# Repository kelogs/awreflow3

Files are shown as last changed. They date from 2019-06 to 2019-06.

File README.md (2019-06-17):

# AW reflow 3

awreflow3 is a reflow oven for soldering PCBs based on [Andy's Workshop awreflow2](http://andybrown.me.uk/2015/07/12/awreflow2/). Technically, this repository contains the missing electric diagram and a layout for the oven, with some modifications in order to suit the parts I had lying around. The purpose of this repository is that you can also pull the files and modify them according to your needs.

## Prerequisites

This project has been developed with [KiCad](http://www.kicad-pcb.org/download/)

## Notes

If you have to order the MOC3020 from the schematic you could get a [MOC3023](https://www.arrow.com/en/products/moc3023/isocom) instead and do away with the Q2 transistor and adjoining resistors.

Other things worth mentioning on the actual oven. Get one based on halogen heating elements just like Andy has done. Mine is a quartz elements oven and the PID is totally useless due to its very high inertia. I had to bypass the PID and hardcode some time intervals where power level is 0% and others where power is driven at 100%. 
At 1000W power and and 9L volume my oven can still bake a full tray of leaded solder PCBs, only a bit slower than others. Here is how it looks:





**NOTE** I currently have 9 extra PCBs already made. If you would like one drop me a message here and I'll deliver it for $3.44 + shipping + Paypal taxes

## License
[MIT](https://choosealicense.com/licenses/mit/)

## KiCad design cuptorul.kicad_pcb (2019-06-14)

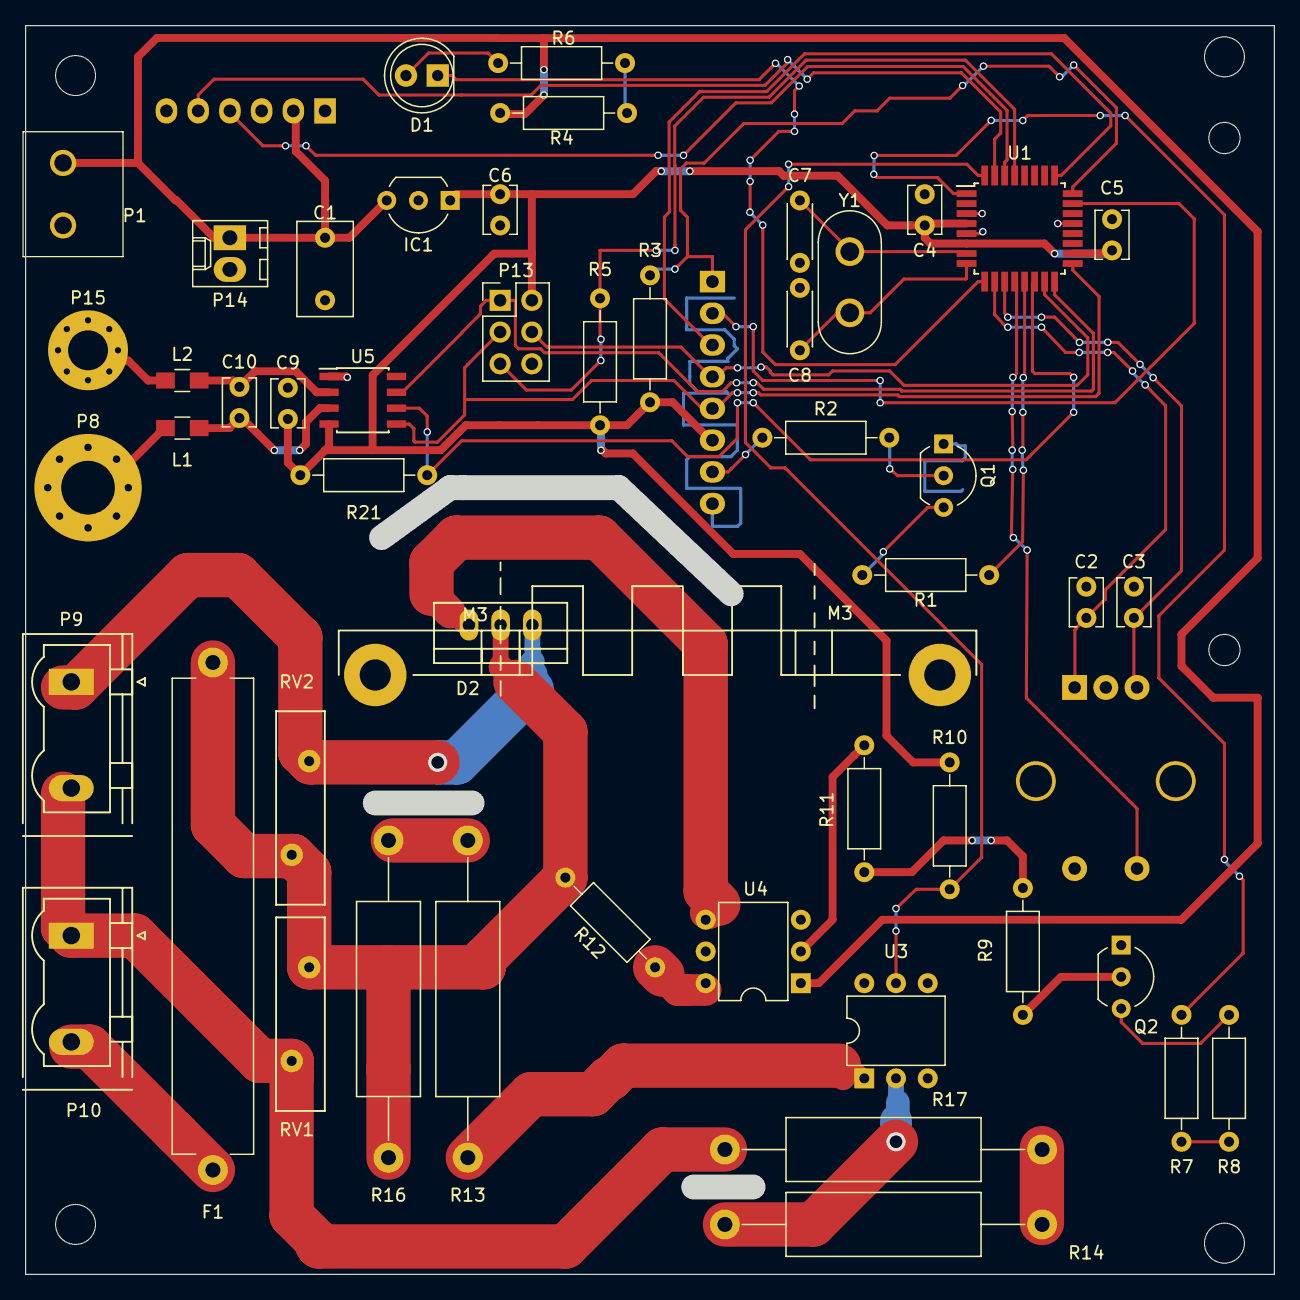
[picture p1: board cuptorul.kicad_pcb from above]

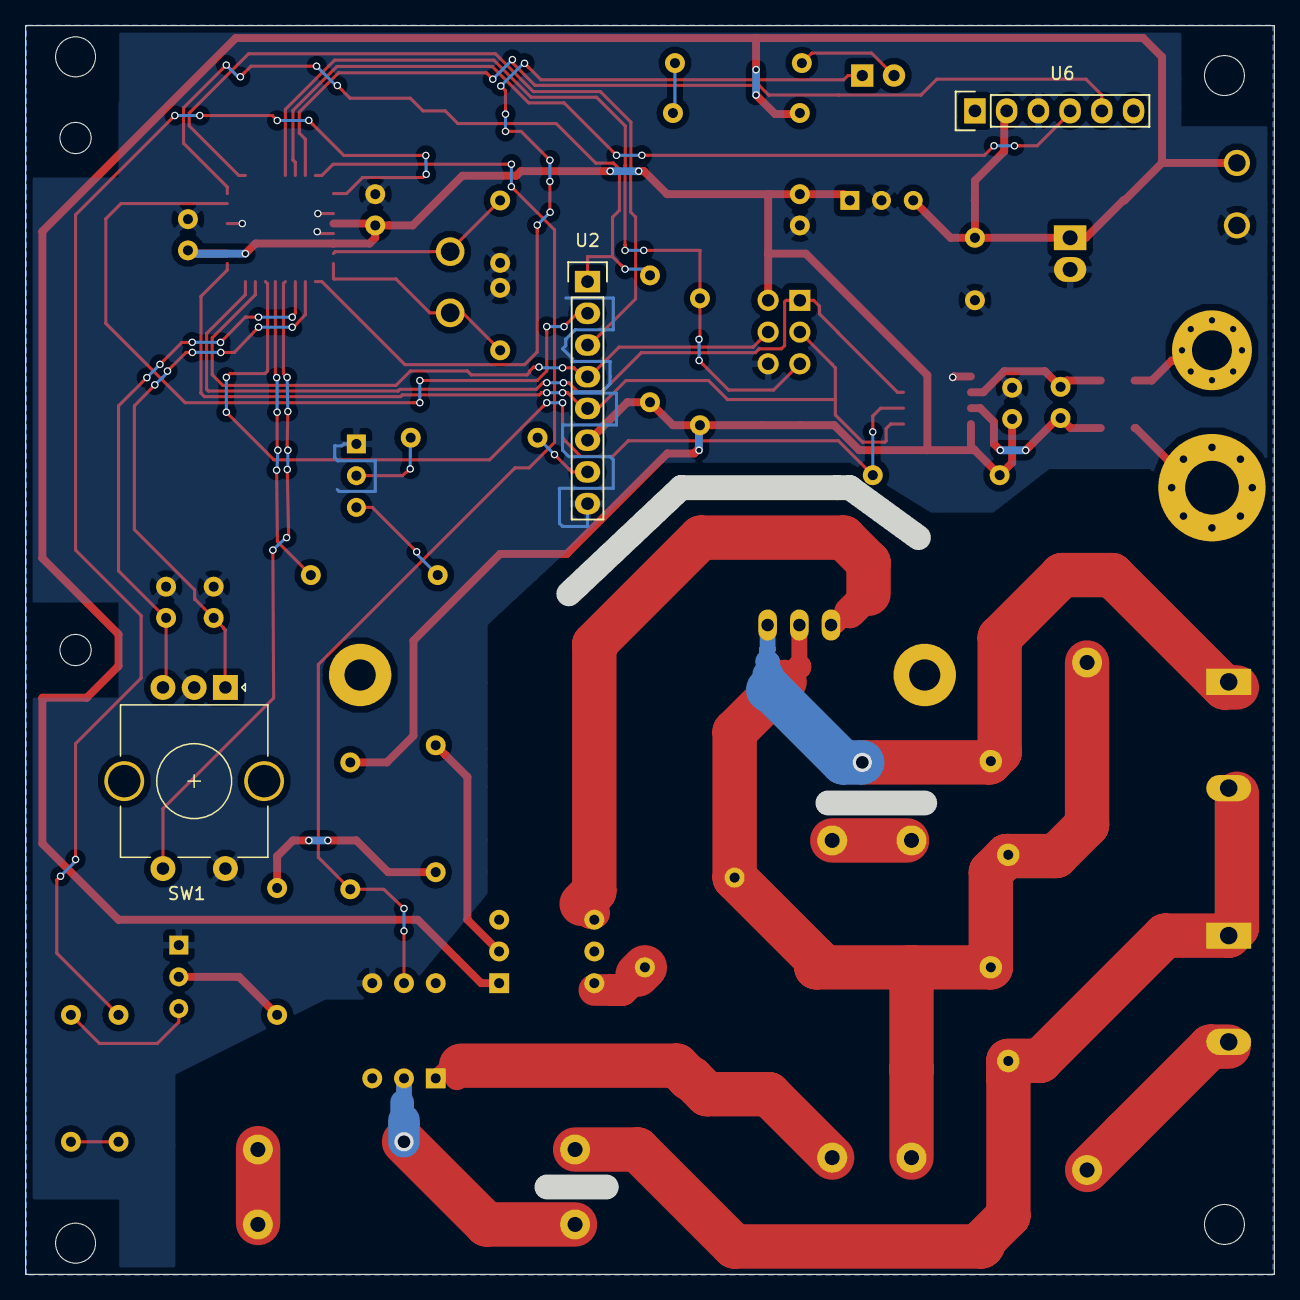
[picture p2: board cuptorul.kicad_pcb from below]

Board: 2 copper layers, 100.0 x 100.0 mm, 52 parts (3 on the bottom side), 46 nets.

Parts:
C1: 330nF; C_Disc_D7.5mm_W4.4mm_P5.00mm
C2, C3, C4, C5, C6, C9: 100nF; C_Disc_D3.8mm_W2.6mm_P2.50mm
C7, C8: 24pF; C_Disc_D4.3mm_W1.9mm_P5.00mm
C10: 10nF; C_Disc_D3.8mm_W2.6mm_P2.50mm
D1: LINK; LED_D5.0mm
D2: TRIAC; TO-220_Neutral123_Vertical
F1: Fuse; R_Axial_Power_L38.0mm_W6.4mm_P40.64mm
IC1: L78L33ACZ; TO-92_Inline_Wide
L1, L2: bead; L_0805_HandSoldering
P1: CONN_5V; em367502v
P8: CONN_TH_COUP_A; MountingHole_4.3mm_M4_Pad_Via
P9: CONN_OVEN; PhoenixContact_GMSTBVA-G_02x7.50mm_Vertical
P10: CONN_MAINS; PhoenixContact_GMSTBVA-G_02x7.50mm_Vertical
P13: CONN_ISP; Pin_Header_Straight_2x03_Pitch2.54mm
P14: CONN_FAN; Molex_KK-6410-02_02x2.54mm_Straight
P15: CONN_TH_COUP_B; MountingHole_3.2mm_M3_Pad_Via
Q1: C945; TO-92_Inline_Wide
Q2: C1815; TO-92_Inline_Wide
R1: 2k1 (1mA); R_Axial_DIN0207_L6.3mm_D2.5mm_P10.16mm_Horizontal
R2: 300 (10mA); R_Axial_DIN0207_L6.3mm_D2.5mm_P10.16mm_Horizontal
R3, R5, R10, R21: 10k; R_Axial_DIN0207_L6.3mm_D2.5mm_P10.16mm_Horizontal
R4, R6: 1k; R_Axial_DIN0207_L6.3mm_D2.5mm_P10.16mm_Horizontal
R7, R8: 300; R_Axial_DIN0207_L6.3mm_D2.5mm_P10.16mm_Horizontal
R9, R11: 47 (40mA); R_Axial_DIN0207_L6.3mm_D2.5mm_P10.16mm_Horizontal
R12: 360; R_Axial_DIN0207_L6.3mm_D2.5mm_P10.16mm_Horizontal
R13, R14, R16, R17: 10k; R_Axial_DIN0516_L15.5mm_D5.0mm_P25.40mm_Horizontal
RV1, RV2: Varistor; RV_Disc_D15.5_W3.9_P7.5
SW1: Rotary_Encoder_Switch; RotaryEncoder_Alps_EC11E-Switch_Vertical_H20mm_CircularMoun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
U1: ATMEGA88-20AU; TQFP-32_7x7mm_Pitch0.8mm
U2: NOKIA5110; Pin_Header_Straight_1x08
U3: OPTO-TRANSISTOR; DIP-6_W7.62mm
U4: MOC3020M; DIP-6_W7.62mm
U5: MAX31855KASA; SOIC-8_3.9x4.9mm_Pitch1.27mm
U6: HC-05-6pin-header; Pin_Header_Straight_1x06
Y1: Crystal; Crystal_HC50_Vertical

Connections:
+3V3: C4.1, C5.1, C6.2, C9.2, IC1.1, P13.2, R3.2, R5.1, R10.1, R21.1, U1.4, U1.6, U1.18, U2.6, U5.4
+5V: C1.2, IC1.3, P1.2, P14.1, R6.1, U4.1, U6.2
GND: C1.1, C2.1, C3.1, C4.2, C5.2, C6.1, C7.1, C8.1, C9.1, IC1.2, P1.1, P13.6, P14.2, Q1.1, Q2.1, SW1.2, SW1.4, U1.3, U1.5, U1.21, U2.8, U3.4, U5.1, U6.3
GNDPWR: P9.2, P10.1, R17.1, RV1.2
unnamed: C2.2, SW1.1, U1.10
unnamed: C3.2, SW1.3, U1.11
unnamed: C7.2, U1.7, Y1.1
unnamed: C8.2, U1.8, Y1.2
unnamed: C10.1, L2.2, U5.2
unnamed: C10.2, L1.2, U5.3
unnamed: D1.1, U1.9
unnamed: D1.2, R4.2
unnamed: D2.1, P9.1, RV2.2
unnamed: D2.2, F1.2, R12.2, R16.1, RV1.1, RV2.1
unnamed: D2.3, U4.4
unnamed: F1.1, P10.2
unnamed: L1.1, P8.1
unnamed: L2.1, P15.1
unnamed: SW1.5, U1.12
unnamed: U1.25, U2.3
unnamed: R3.1, U1.24, U2.1
unnamed: U1.23, U2.2
unnamed: R2.1, U2.7
unnamed: U1.31, U6.5
unnamed: U1.30, U6.4
unnamed: P13.1, U1.16, U5.7
unnamed: P13.3, U1.17, U2.5, U5.5
unnamed: P13.4, U1.15, U2.4
unnamed: P13.5, R5.2, U1.29
unnamed: Q1.2, R2.2
unnamed: Q1.3, R1.1
unnamed: Q2.2, R9.2
unnamed: Q2.3, R8.1
unnamed: R1.2, U1.13
unnamed: R4.1, R6.2
unnamed: R7.1, R8.2
unnamed: R7.2, U1.1
unnamed: R10.2, U1.32, U3.5
unnamed: R11.1, U4.2
unnamed: R9.1, R11.2
unnamed: R12.1, U4.6
unnamed: R13.1, R16.2
unnamed: R13.2, U3.1
unnamed: R14.1, R17.2
unnamed: R14.2, U3.2
unnamed: R21.2, U1.14, U5.6
